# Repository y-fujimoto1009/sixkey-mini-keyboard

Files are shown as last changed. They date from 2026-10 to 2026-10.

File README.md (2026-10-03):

# 6キー ミニキーボード（RP2040-Zero）

RP2040-Zero、6個のMX互換キースイッチ、押し込み付きEC11エンコーダー、0.96インチST7735 LCDを使ったミニキーボードです。

## キー配置を設定する

**[キーマップ設定サイトを開く](https://y-fujimoto1009.github.io/sixkey-mini-keyboard/)**

6個のキーとエンコーダーの右回転・左回転・押し込みに操作を割り当て、設定JSONを保存できます。USB経由で本体を設定するときは、パソコン版Chrome / Edgeと対応ファームウェアを使用します。

上段はK4・K5・K6、下段はK1・K2・K3です。サイトのUSB接続後、読み込み・保存はそれぞれのボタンで行います。

## 本体LCDで遊ぶミニゲーム

現行は**Play V2.4**です。Command+C/V/X/Z/S/AとAlt+A/Vを追加しました。既存のCtrl設定は変更しません。Macでは設定サイトの「Mac（Command）」から選択し、USB設定にはChrome / Edgeを使います。AltはMacではOptionです。追加操作にはConfig V1.2またはPlay V2.4への本体更新が必要です。Ctrlと文字を同時に送る修正も維持しています。Mac実機での動作確認は未完了です。本体の色確認画面でRGB/BGRと反転設定を切り替え、実物に合う設定を保存できます。実機での表示・保存確認は未完了です。

[設定サイトのミニゲーム欄](https://y-fujimoto1009.github.io/sixkey-mini-keyboard/#games)から、[3ゲーム入りUF2](docs/sixkey-play-v2.4.uf2)をダウンロードできます。

- **うさぎのぴょんぴょん散歩**：ジャンプで20個のきのこを飛び越えるアクション。
- **ねこのおやつあつめ**：左右に動いていちごを20個集めるキャッチゲーム。
- **お花のきおくあそび**：光る順番を覚え、K1〜K3で答える8段の記憶パズル。

BOOT接続してRPI-RP2にUF2をコピーすると、3つまとめて本体に入ります。ゲーム中はPCへのHID入力を止めます。ゲームの進行は10項目のCPUエミュレーター検証、サイトの接続処理は模擬シリアル通信で検証済みです。キーボード機能とキー設定の保存形式も含む共通ファームです。

メニューではK1・K3で選択、K2で決定。ゲーム中K6でメニュー、終了後K2でリトライ。メニューのK6でキーボードへ戻ります。キーボードからはK4+K6を約1.2秒長押し（割り当て済みの入力もPCへ送信）。サイトのUSB開始ボタンからもゲームを選べます。

[ゲーム入りソース](firmware/SixKey_Play/)と[通信・ビルド仕様](docs/protocol.md)を公開しています。実機への書き込み・LCD表示・ゲーム操作・設定保持は未検証です。

## ダウンロード

| 内容 | ファイル |
| --- | --- |
| Rev8 ガーバー・ドリル一式 | [Gerber ZIP](hardware/sixkey-rev8-gerbers.zip) |
| 回路図 | [Rev8 回路図PDF](hardware/schematic-rev8.pdf) |
| 部品付き基板の3Dモデル（mm） | [STL](models/keyboard-assembly-mm.stl) / [STEP](models/keyboard-assembly.step) |
| 基板だけの3Dモデル（mm） | [STL](models/pcb-only-mm.stl) |
| 個別部品を含む3Dモデル一式 | [3Dモデル ZIP](models/sixkey-3d-models.zip) |
| 設定サイト用ファームウェア | [UF2](docs/sixkey-config-v1.2.uf2) / [ソース](firmware/SixKey_Config/SixKey_Config.ino) |

ガーバーの版と確認範囲は[基板の説明](hardware/README.md)、Tinkercadへの取り込み方法と仮寸法は[3Dモデルの説明](models/README.md)を参照してください。

## 確認状況

設定JSON、75種類の割り当て、ファームウェアとの操作番号の一致、UF2形式はソフトウェア検証済みです。本体へのUSB書き込み・電源再投入後の保持・新しいファームウェアのLCD/HID動作は実機未検証です。

UF2を書き込むと本体の既存ファームウェアを置き換えます。設定サイト内の手順を確認してください。[通信仕様](docs/protocol.md)も公開しています。

## サイトを更新する

`docs/`がGitHub Pagesの公開フォルダーです。`main`へ更新をpushするとサイトが更新されます。Node.jsで`npm test`を実行するとソフトウェア検証を行えます。

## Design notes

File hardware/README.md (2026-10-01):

# Rev8 基板データ

既存のRev8製造出力を保存した参照データです。別の版のファイルは混在させていません。

- 基板外形：84 × 73.05 mm、想定板厚1.6 mm。
- 表裏の銅箔・レジスト・シルク、外形、PTH/NPTHドリル、GerberジョブファイルをZIPに収録。
- 元のRev8ソースの確認記録ではERC・DRC・未接続・回路図との不一致は0件。
- 穴はPTH 50か所、NPTH 26か所。基板固定穴4か所とLCD固定穴4か所を含みます。

元プロジェクトの注意事項：Rev8を発注する場合は、対象プロジェクトからGerberとドリルを新規生成して最終確認してください。この公開は既存出力の共有であり、新たな製造承認を示すものではありません。

`SHA256SUMS.txt`で公開ファイルのハッシュを確認できます。

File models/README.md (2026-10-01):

# ケース設計用3Dモデル

## Tinkercadで使う

1. `keyboard-assembly-mm.stl`をダウンロードする。
2. Tinkercadの新しいデザインで「インポート」を開き、STLを選ぶ。
3. 単位はmm、倍率は100%にする。部品付きモデルの幅は約84 mmです。
4. モデルを基準にケースを作る。完成後はケースだけを選択してSTLをエクスポートする。

基板だけを使う場合は`pcb-only-mm.stl`、CADで扱う場合はSTEPを使います。`parts/`にはRP2040-Zero、LCD、EC11＋ノブ、MXスイッチ＋キーキャップの個別モデルを収録しています。

## 寸法・確認範囲

- 基板：84 × 73.05 × 1.6 mm。
- 部品付きSTLの外接寸法：約84 × 73.255 × 34.3 mm。
- STLは閉じたメッシュとして検証済み。Tinkercadへの実際の取り込みとケースの実物適合は未確認です。
- LCDの基板からの突出10.5 mm、RP2040-Zeroの裏面突出8.7 mm、EC11の軸・ノブ寸法、MXスイッチ・キーキャップ高さは仮寸法です。実物で確認してください。
- はんだの盛り、端子の突出、ネジ頭、USBケーブルのプラグ、キーの動作範囲を完全には再現していません。ケースにはこれらの余裕も確保してください。
- STEP内の長穴は小さい側の穴径の円で簡略化しています。基板STLは元のドリル形状を反映しています。

このモデルは配置とケース検討の参考モデルです。

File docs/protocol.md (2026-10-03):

# 6キー設定 V1

JSON: format = sixkey-keymap, version = 1, keys = K1〜K6の6要素。
encoder.clockwise / counterclockwise / press が回転・押し込み。
割り当て番号の定義は model.js の actions にあり、ファームの validAction と対応。

USB CDC 115200 bps / LF終端、ASCII。
読み出し: `K6/1 GET`
保存: `K6/1 SET 49,50,51,52,53,54,2001,2002,2003`
応答: `K6/1 MAP ` に続いて上記9番号。拒否: `K6/1 ERR 理由`。
保存時は入力を検証し、HIDを解放、EEPROMエミュレーションへ保存して物理フラッシュを読み戻す。
サイトはACKと再取得を照合する。再接続後の保持は実機で確認すること。
フラッシュ書き込み中の電源断では初期設定へ戻る可能性がある。

初期値: K1〜K6 = 1〜6、右回転 = 音量上、左回転 = 音量下、押し込み = ミュート。
英字の表示は大文字だが、送信は通常の文字キー（大文字化はShift/Caps Lock依存）。
キーと押し込みは押している間有効。エンコーダー回転とメディア操作は短い入力。
同時押しはUSBの6キー制限がある。CtrlショートカットはWindows/Linux向け。
V1はゲームを含みません。Play V2は3ゲームとキーボードを含みます。更新は利用者がBOOTモードで明示的に行います。

ビルド: Arduino-Pico 5.5.0、Waveshare RP2040 Zero、125MHz、2MB Flash / no filesystem、Pico SDK USB。
ライブラリ: Adafruit GFX、Adafruit ST7735/ST7789、コア標準Keyboard・SPI・EEPROM。
配線: LCD SCK=GP2, MOSI=GP3, DC=GP4, CS=GP5, RESET=GP6, BLK=GP7。
K1〜K6=GP26,27,28,13,14,15。エンコーダーA/B/押し込み=GP10,11,12。
液晶初期化と回転は動作実績のある設定を維持。実機での新ファーム動作は未検証。

## Play V2（ゲーム入り）

`K6/1 CAPS` → `K6/1 CAPS PLAY2`。旧V1は未対応コマンドとしてERRを返します。
`K6/1 GAME 0` → キーボード、1 → ジャンプ、2 → キャッチ、3 → 記憶パズル。
応答は`K6/1 GAME 番号`。0〜3の単一数字だけを受け付けます。
切り替え時はHIDを解放し、全キーを離して500ms経過するまで入力を受け付けません。
ゲーム中はHIDキー・メディア操作を送信しません。GET/SETによるキー設定は維持し、SETが成功するとキーボードへ戻ります。
モードはRAM内だけで管理し、電源投入時はゲームメニューです。K1で前、K3で次、K2で決定、K6でキーボードへ。
ゲーム中はK6でメニュー、終了後はK2でリトライ。キーボード中はK4+K6を約1.2秒長押しでメニューへ戻ります。この長押しでは割り当て済みのキー入力もPCに送られます。

Play V2ソースは`firmware/SixKey_Play/`の2ファイルを同じフォルダーに置きます。ボードとライブラリはV1と同じです。

```sh
arduino-cli compile --fqbn rp2040:rp2040:waveshare_rp2040_zero:flash=2097152_0,freq=125,usbstack=picosdk --output-dir build firmware/SixKey_Play
```

ゲームロジックのCortex-M0エミュレーター検証は`tests/README.md`を参照してください。LCD・USB・GPIOと実物の遊び心地は実機未検証です。

### Play V2.1：液晶の色順を修正

利用者の実機報告「赤と青が入れ替わる」に対応し、MINI160x80の初期化・回転3の後でMADCTLをMX | MV | BGRに設定します。回転・オフセット・RGB565描画データは変更しません。赤青の順序だけを変更し、通信仕様のCAPS PLAY2も維持します。修正後の実機表示確認は未完了です。

### Play V2.2：色の確認と保存

初回（表示設定なし）は色確認画面。K1でRGB/BGR、K2でINVON/INVOFFを切り替え、K5でEEPROMの64番地に表示設定を保存して物理フラッシュを読み戻します。保存成功はSAVED表示。キー設定と保存領域は重なりません。K6でメニューへ。保存後の起動はメニューになり、メニューK4で再調整できます。正しい色順と反転設定は実機のテストパターンで判断するもので、こちらでは未確定です。

## Config V1.2 / Play V2.4：Mac・Alt

1001〜1006は従来どおりCtrl+C/V/X/Z/S/A。1101〜1106はCommand+C/V/X/Z/S/A（左GUI修飾、HIDマスク0x08）。1201・1202はAlt+A・Alt+V（左Alt修飾、0x04）。MacではAltはOptionとして動作し、結果はアプリ・入力言語に依存します。既存設定をOSに応じて自動変換しません。

設定ファイルversionと通信K6/1は維持。新しい操作IDを保存する前に本体も更新してください。旧ファームは新IDを拒否します。MacのUSB設定にはWeb Serial対応のChrome / Edgeを使用します。Mac実機でのHID・保存・再起動は未検証です。

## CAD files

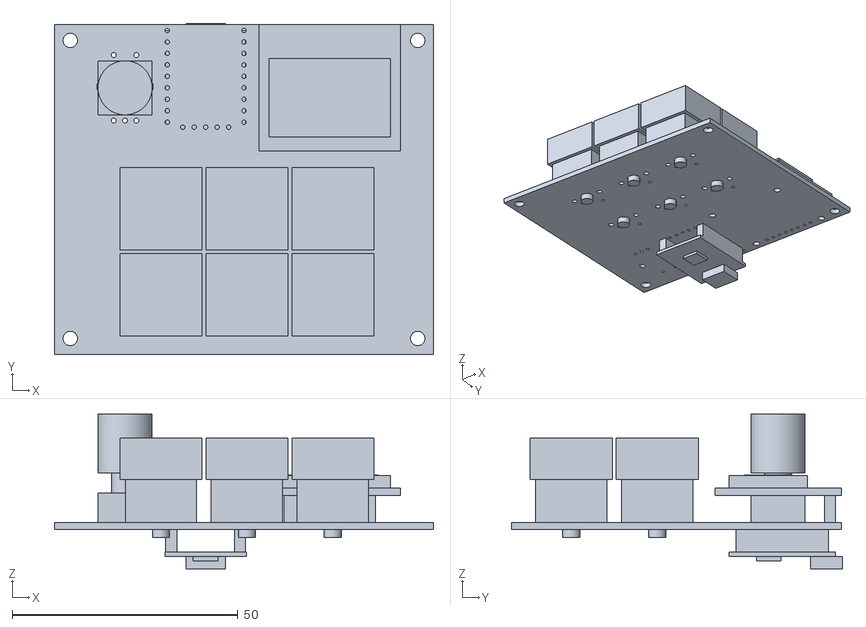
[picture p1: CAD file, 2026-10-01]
models/keyboard-assembly-mm.stl
84.0 x 73.3 x 34.3

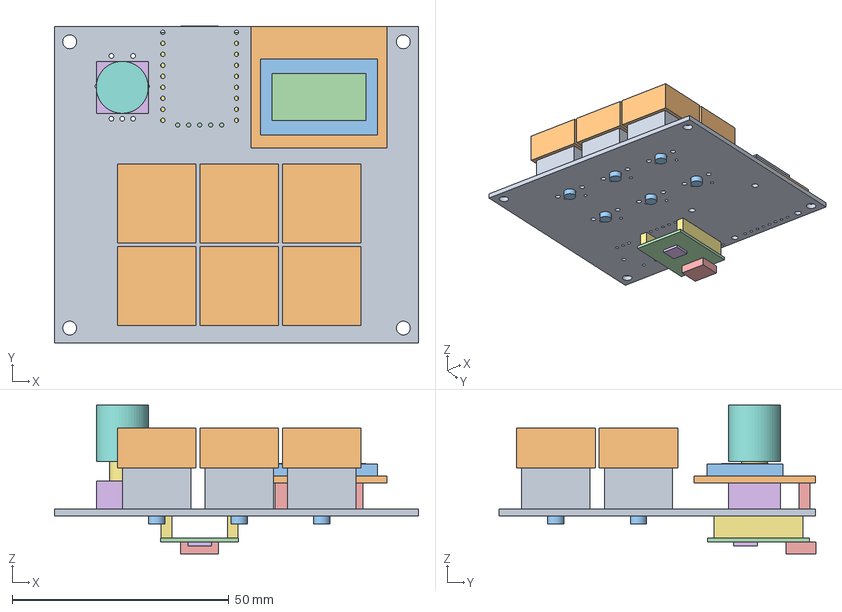
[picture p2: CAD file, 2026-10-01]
models/keyboard-assembly.step
84.0 x 73.3 x 34.3 mm

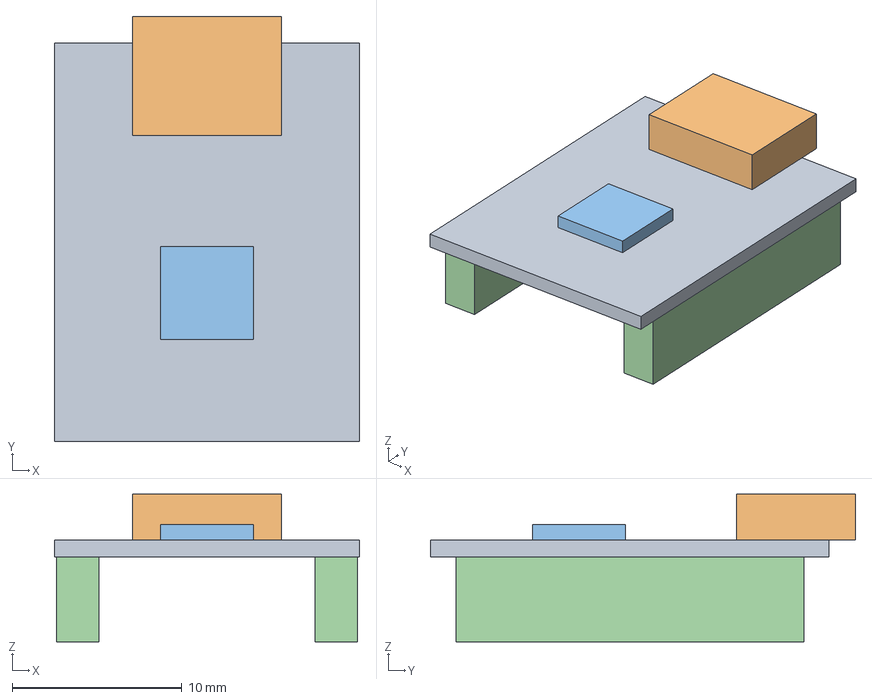
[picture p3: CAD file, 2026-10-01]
models/parts/RP2040_ZERO.step
18.0 x 25.1 x 8.70 mm

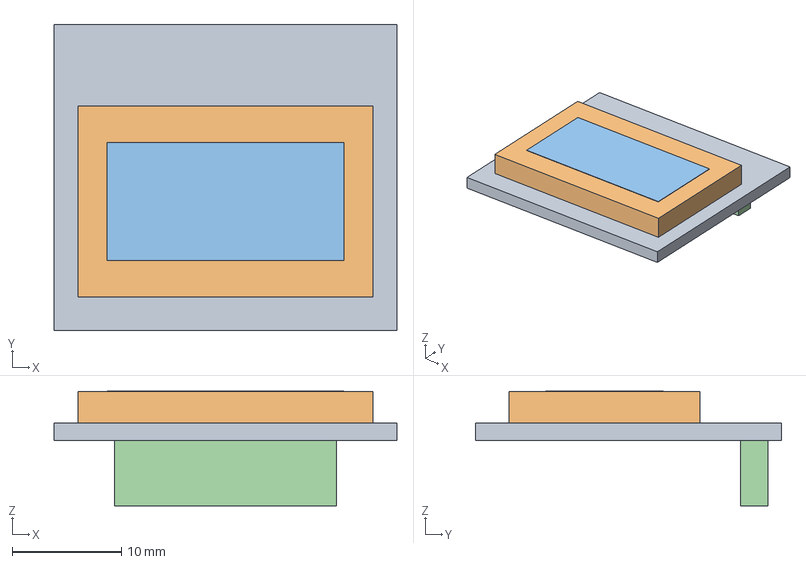
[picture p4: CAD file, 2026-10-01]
models/parts/LCD_ST7735.step
31.4 x 28.0 x 10.5 mm

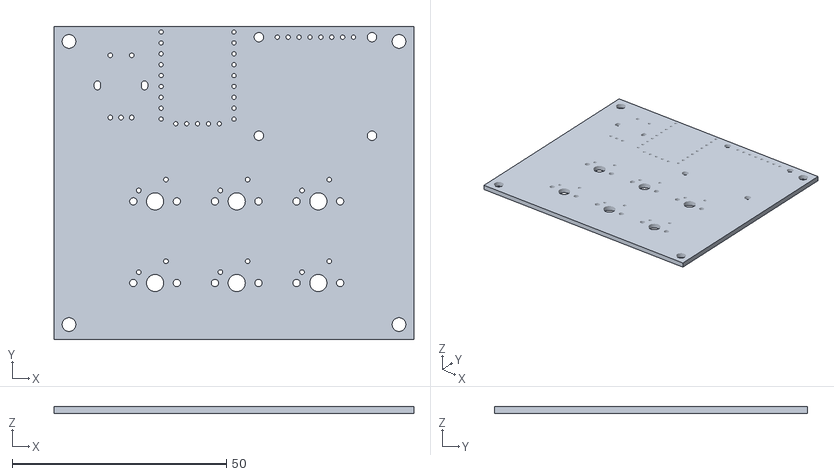
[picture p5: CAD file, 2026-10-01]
models/pcb-only-mm.stl
84.0 x 73.0 x 1.60

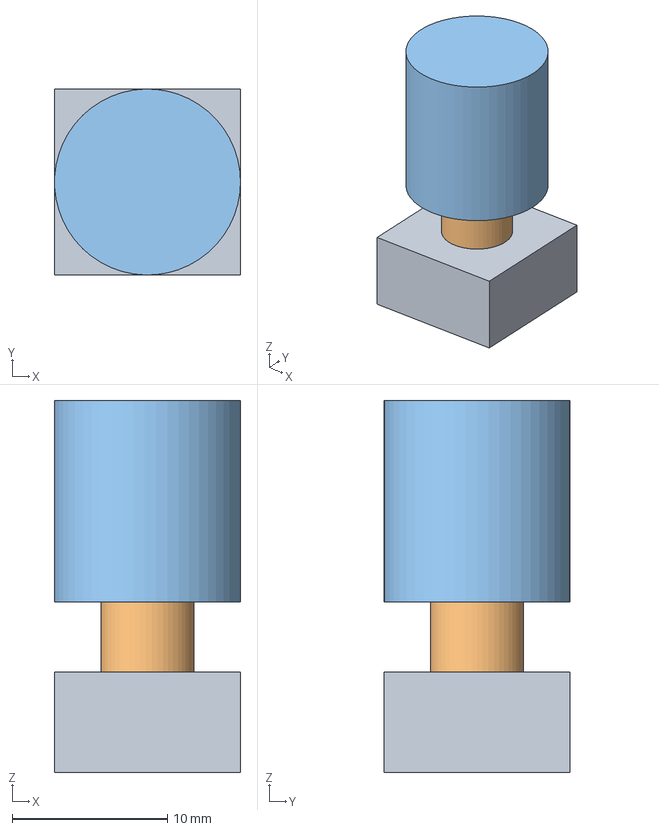
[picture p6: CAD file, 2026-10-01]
models/parts/EC11_WITH_KNOB.step
12.0 x 12.0 x 24.0 mm

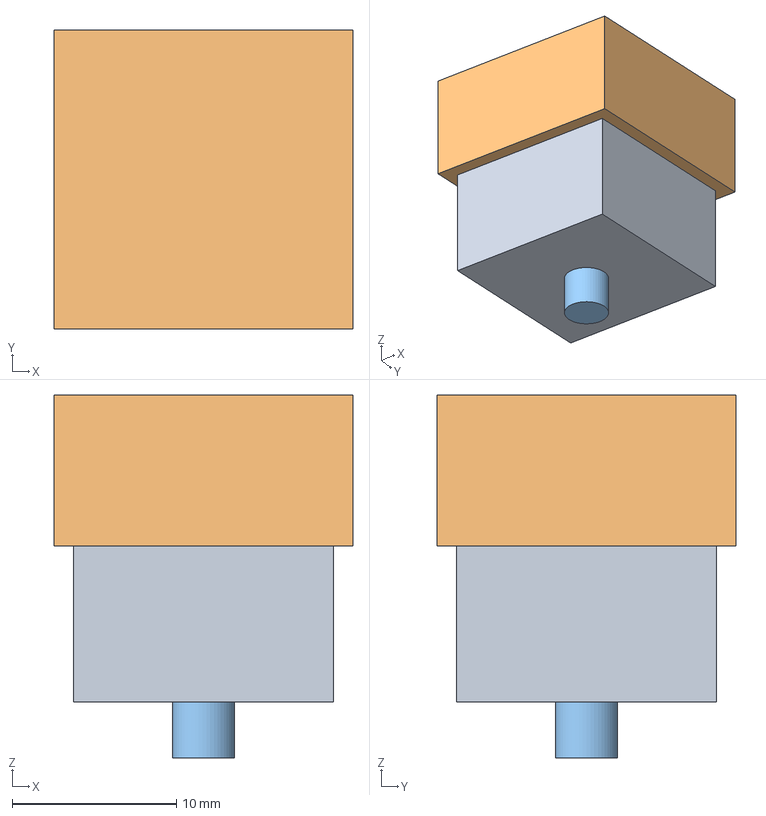
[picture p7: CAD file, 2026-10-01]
models/parts/MX_WITH_KEYCAP.step
18.2 x 18.2 x 22.1 mm

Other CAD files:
models/parts/EC11_WITH_KNOB.obj
models/parts/EC11_WITH_KNOB.stl
models/parts/LCD_ST7735.obj
models/parts/LCD_ST7735.stl
models/parts/MX_WITH_KEYCAP.obj
models/parts/MX_WITH_KEYCAP.stl
models/parts/RP2040_ZERO.obj
models/parts/RP2040_ZERO.stl

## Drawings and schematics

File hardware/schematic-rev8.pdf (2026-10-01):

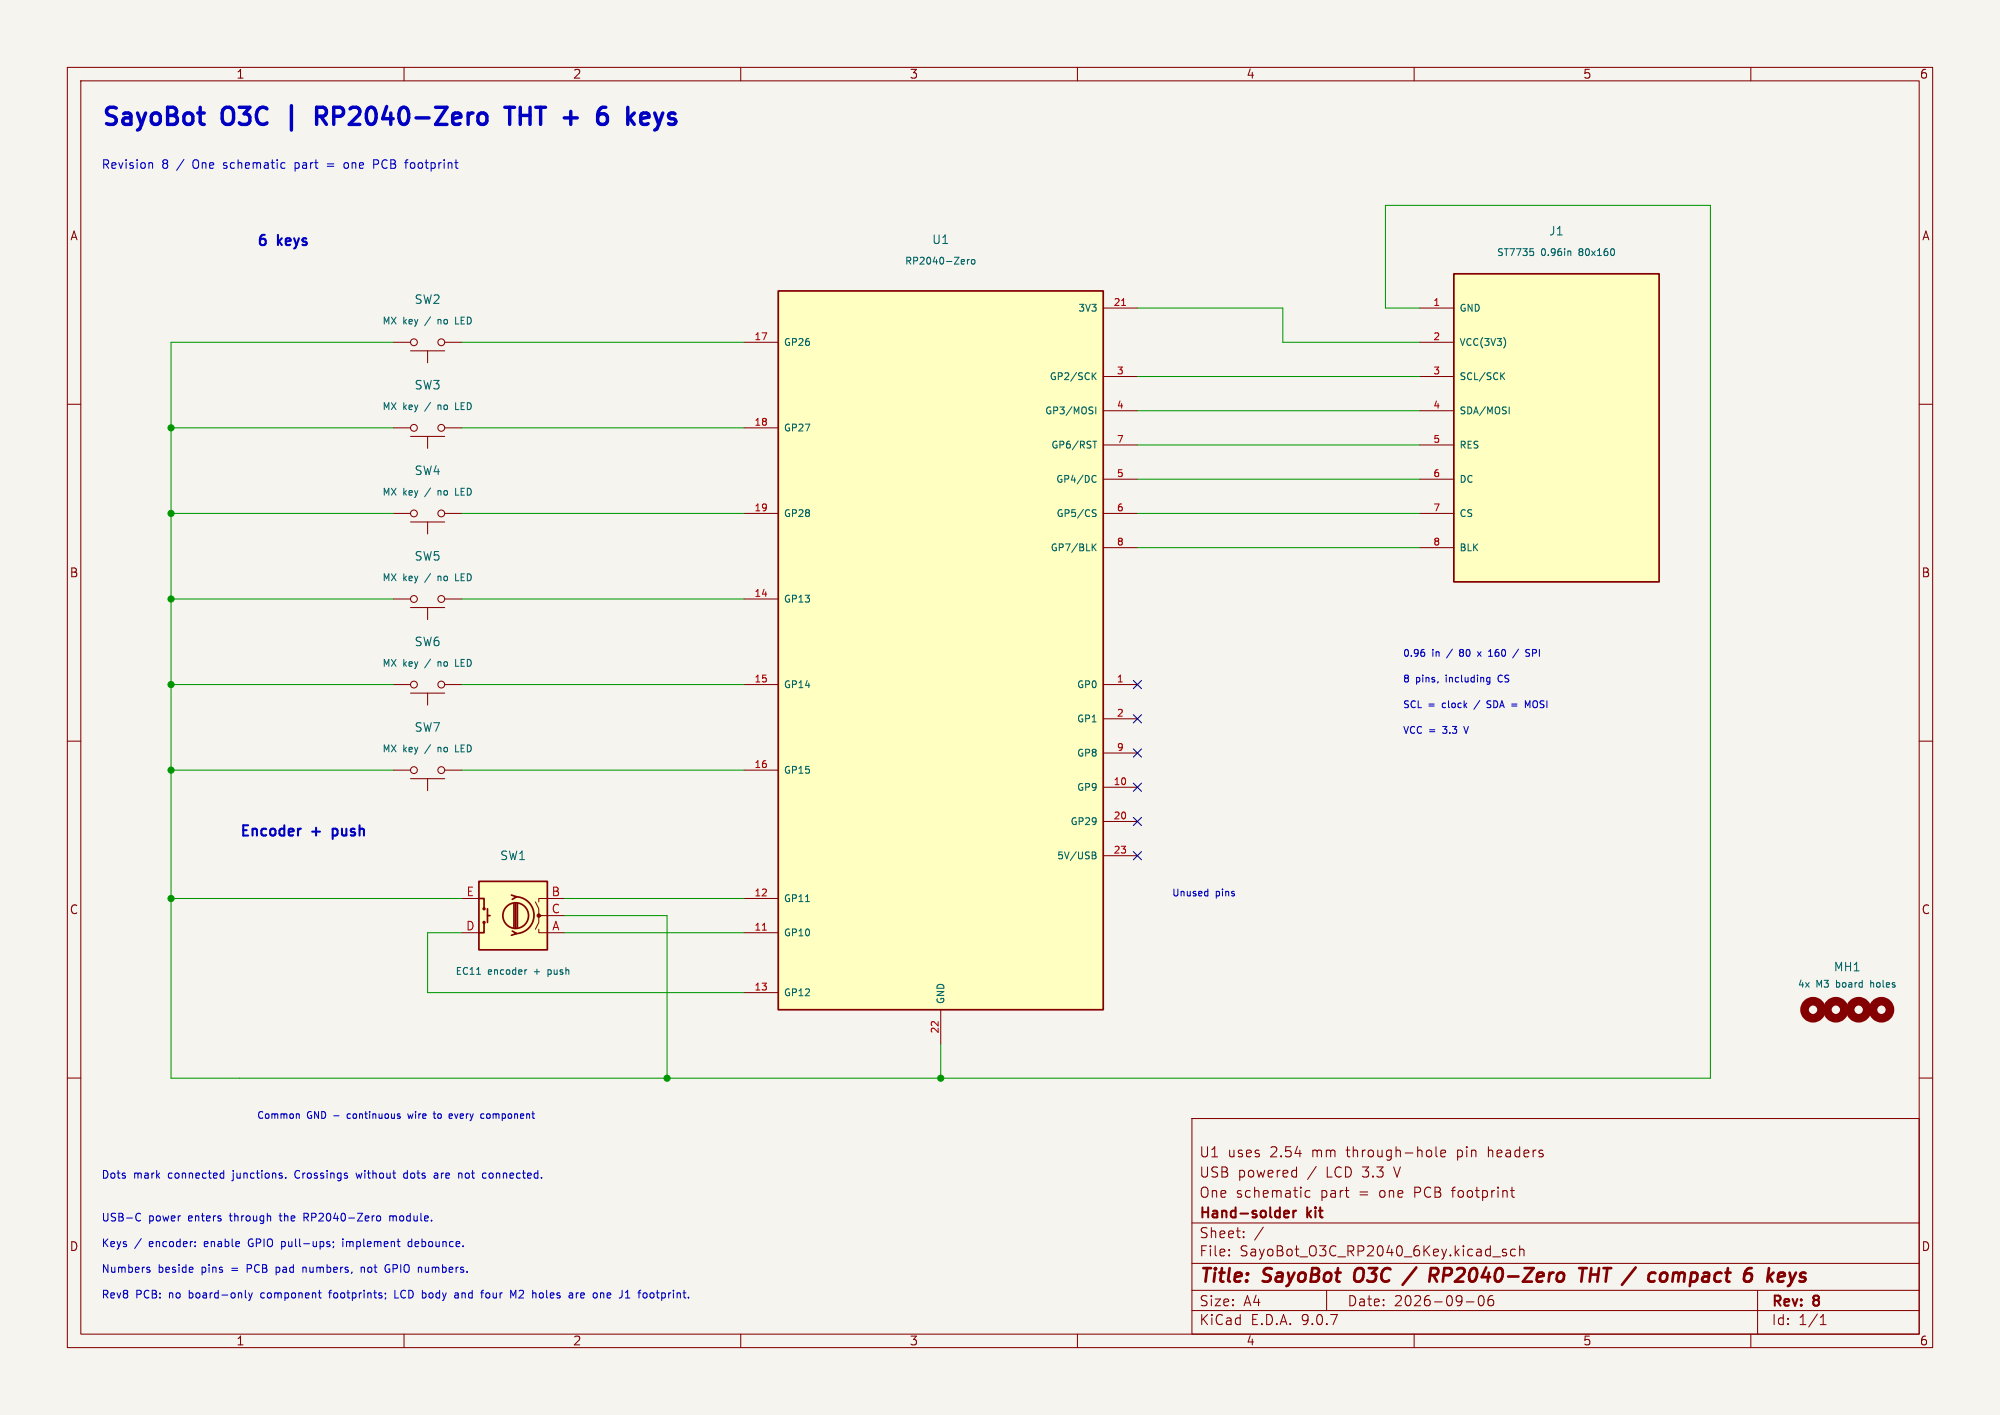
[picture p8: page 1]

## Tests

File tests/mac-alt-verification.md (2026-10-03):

# Mac / Alt update — 2026-10-03

- Config V1.2 and Play V2.4 compiled successfully for Waveshare RP2040 Zero with Arduino-Pico 5.5.0.
- Authoritative modifier definitions: installed HID_Keyboard.h defines left Ctrl=128, Alt=130, GUI=131. The HID implementation maps them to modifier bits 0x01, 0x04, 0x08.
- Mac Command uses GUI; Alt is Option. Reference: https://support.apple.com/en-us/102650
- Mac USB configuration requires desktop Web Serial support, e.g. Chrome: https://developer.chrome.com/docs/capabilities/serial
- npm test passed: all 83 action IDs match both firmware validators, JSON/serial round trips, invalid input rejection, downloadable source equality, UF2 structure and game compatibility.
- Actual addAction/syncHeld/tap bodies were exercised with modeled USB transport for all 14 Ctrl/Command/Alt shortcuts. Chords are emitted together and release correctly.
- Real app.js was exercised against a simulated serial device: Command, Alt and existing Ctrl settings saved and read back through the UI.
- Both downloadable UF2 payloads were byte-compared with their compiled BIN files. Flash addresses exclude the EEPROM sector.
- Existing Ctrl IDs, GPIO assignments, keymap format, games and display settings are preserved. New IDs require the updated firmware.

Not verified: physical Mac/Windows USB HID operation, physical flash writes, power-cycle persistence, LCD appearance. Automated transport tests are simulations, not device tests.

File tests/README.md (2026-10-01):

# ゲームロジックの検証

`Games.h`をCortex-M0向けにコンパイルし、Unicornで実行します。メニュー選択、ジャンプの失敗と20個クリア、キャッチの移動端・失敗・クリア、記憶パズルの入力待ち・8段クリア・間違いを検証します。

描画はスタブ、LCD・USB・GPIOなどの周辺機器は未再現です。実機確認の代わりにはなりません。

```sh
python -m pip install unicorn pyelftools
arm-none-eabi-g++ -mcpu=cortex-m0plus -mthumb -Os -ffreestanding -fno-exceptions -fno-rtti -nostdlib -I tests tests/game_logic.cpp -Wl,-Ttext=0x10000000,-Tdata=0x20000000,-e,run_game_tests -lc -lgcc -o game-tests.elf
python tests/run_arm_tests.py game-tests.elf
```

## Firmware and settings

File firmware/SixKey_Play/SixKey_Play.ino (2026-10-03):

#include <Adafruit_GFX.h>
#include <Adafruit_ST7735.h>
#include <Keyboard.h>
#include <SPI.h>
#include <EEPROM.h>
#include <USB.h>
#include <tusb.h>

// Build a complete chord before sending it. Sending ASCII first and Ctrl
// second produces a plain letter; a busy USB endpoint can also drop Ctrl.
class ChordKeyboard : public Keyboard_ {
  KeyReport pendingReport={};
  bool pendingReportDirty=false;
protected:
  void sendReport(KeyReport *report) override {
    pendingReport=*report;
    pendingReportDirty=true;
  }
public:
  bool flushReport() {
    if(!pendingReportDirty)return true;
    if(!_running)return false;
    CoreMutex lock(&USB.mutex);
    tud_task();
    if(USB.HIDReady() && tud_hid_keyboard_report(USB.findHIDReportID(_id),pendingReport.modifiers,pendingReport.keys))pendingReportDirty=false;
    tud_task();
    return !pendingReportDirty;
  }
  bool waitReport() {
    uint32_t started=millis();
    while(!flushReport()) {
      if(millis()-started>=40)return false;
      delay(1);
    }
    return true;
  }
};
ChordKeyboard chordKeyboard;
#include "Games.h"
GFXcanvas16 frame(160,80);
uint32_t gameFrameAt=0,menuHoldAt=0;
bool menuChordLatched=false;
constexpr TinyGames::Scene COLOR_TEST=static_cast<TinyGames::Scene>(5);
constexpr int DISPLAY_CONFIG_OFFSET=64;
struct DisplayConfig { uint32_t magic;uint8_t bgr,invert,check,reserved; };
DisplayConfig displayConfig={0x434f4c32,1,1,0xa6,0};
bool displaySaved=false;
void applyDisplay();
void drawColorTest();
void setScene(TinyGames::Scene scene);
void drawGame();

// RP2040-Zero: preserve the pin assignments of the working hardware.
constexpr uint8_t KEY_PINS[7]={26,27,28,13,14,15,12};
constexpr uint8_t LCD_SCK=2,LCD_MOSI=3,LCD_DC=4,LCD_CS=5,LCD_RST=6,LCD_BLK=7;
constexpr uint8_t ENC_A=10,ENC_B=11;
constexpr uint16_t DEFAULTS[9]={49,50,51,52,53,54,2001,2002,2003};
constexpr uint32_t MAGIC=0x364b0001;
struct Config{uint32_t magic;uint16_t map[9];uint16_t checksum;};
static_assert(sizeof(Config)<=DISPLAY_CONFIG_OFFSET,"Display settings must not overlap keymap");
struct Button{bool raw,down;uint32_t changed;};
Config config;
Button buttons[7];
bool sent[256]={},armed=false;
uint32_t releasedAt=0;
uint8_t encPrevious;
int8_t quarters=0;
char line[120];size_t used=0;bool overflow=false;
Adafruit_ST7735 tft(&SPI,LCD_CS,LCD_DC,LCD_RST);

bool validAction(uint16_t a){return a==0||a==32||(a>=48&&a<=57)||(a>=97&&a<=122)||(a>=128&&a<=131)||(a>=176&&a<=179)||(a>=194&&a<=205)||(a>=212&&a<=212)||(a>=215&&a<=218)||(a>=1001&&a<=1006)||(a>=1101&&a<=1106)||(a>=1201&&a<=1202)||(a>=2001&&a<=2006);}
uint16_t checksum(const Config &c){uint16_t h=0x6b31;for(auto a:c.map)h=(h*31)^a;return h;}
bool validConfig(const Config &c){if(c.magic!=MAGIC||c.checksum!=checksum(c))return false;for(auto a:c.map)if(!validAction(a))return false;return true;}
void releaseHid(){chordKeyboard.releaseAll();chordKeyboard.waitReport();chordKeyboard.consumerRelease();memset(sent,0,sizeof(sent));}
void draw(){if(TinyGames::scene!=TinyGames::KEYS){drawGame();return;}tft.fillScreen(ST77XX_BLACK);tft.setTextSize(1);tft.setTextColor(ST77XX_WHITE);tft.setCursor(3,3);tft.print("6KEY PLAY V2.4");for(int i=0;i<6;i++){int x=(i%3)*53,y=18+(i<3?23:0);tft.fillRoundRect(x+1,y,50,20,3,buttons[i].down?ST77XX_GREEN:ST77XX_BLUE);tft.setCursor(x+4,y+6);tft.print(i+1);tft.print(':');tft.print(config.map[i]);}tft.setCursor(3,68);tft.print(armed?"K4+K6: MENU":"Release all keys");}
void report(){Serial.print("K6/1 MAP ");for(int i=0;i<9;i++){if(i)Serial.print(',');Serial.print(config.map[i]);}Serial.println();}
void command(){
  line[used]=0;
  if(!strcmp(line,"K6/1 CAPS")){Serial.println("K6/1 CAPS PLAY2");return;}
  if(!strncmp(line,"K6/1 GAME ",10)){
    if(line[10]>='0'&&line[10]<='3'&&line[11]==0){int id=line[10]-'0';setScene(id==0?TinyGames::KEYS:static_cast<TinyGames::Scene>(id));Serial.print("K6/1 GAME ");Serial.println(id);}else Serial.println("K6/1 ERR GAME");return;
  }
  if(!strcmp(line,"K6/1 GET")){report();return;}
  if(strncmp(line,"K6/1 SET ",9)){Serial.println("K6/1 ERR COMMAND");return;}
  Config next={};next.magic=MAGIC;const char *p=line+9;
  for(int i=0;i<9;i++){
    if(*p<'0'||*p>'9'){Serial.println("K6/1 ERR FORMAT");return;}
    unsigned value=0;while(*p>='0'&&*p<='9'){value=value*10+(*p++-'0');if(value>3000){Serial.println("K6/1 ERR RANGE");return;}}
    if(!validAction(value)||(*p!=(i==8?'\0':','))){Serial.println("K6/1 ERR VALUE");return;}
    next.map[i]=value;if(i<8)p++;
  }
  next.checksum=checksum(next);releaseHid();armed=false;releasedAt=0;quarters=0;
  EEPROM.put(0,next);if(!EEPROM.commit()){Serial.println("K6/1 ERR FLASH");return;}
  // begin() re-reads physical flash rather than merely checking the RAM buffer.
  EEPROM.begin(256);Config saved={};EEPROM.get(0,saved);
  if(!validConfig(saved)||memcmp(&saved,&next,sizeof(next))){Serial.println("K6/1 ERR VERIFY");return;}
  config=saved;setScene(TinyGames::KEYS);draw();report();
}
void serialPoll(){int budget=128;while(Serial.available()&&budget--){char c=Serial.read();if(c=='\r')continue;if(c=='\n'){if(overflow)Serial.println("K6/1 ERR LENGTH");else command();used=0;overflow=false;}else if(used<sizeof(line)-1&&!overflow)line[used++]=c;else overflow=true;}}
void addAction(bool *desired,uint16_t a){if(a>0&&a<256)desired[a]=true;else if(a>=1001&&a<=1006){const char keys[]="cvxzsa";desired[KEY_LEFT_CTRL]=true;desired[(uint8_t)keys[a-1001]]=true;}else if(a>=1101&&a<=1106){const char keys[]="cvxzsa";desired[KEY_LEFT_GUI]=true;desired[(uint8_t)keys[a-1101]]=true;}else if(a>=1201&&a<=1202){const char keys[]="av";desired[KEY_LEFT_ALT]=true;desired[(uint8_t)keys[a-1201]]=true;}}
void mediaTap(uint16_t a){if(a<2001||a>2006)return;const uint16_t codes[]={0xe9,0xea,0xe2,0xcd,0xb5,0xb6};chordKeyboard.consumerPress(codes[a-2001]);delay(12);chordKeyboard.consumerRelease();}
void syncHeld(){bool desired[256]={};for(int i=0;i<7;i++)if(buttons[i].down)addAction(desired,config.map[i==6?8:i]);for(int i=1;i<256;i++)if(sent[i]&&!desired[i])chordKeyboard.release(i);for(int i=1;i<256;i++)if(!sent[i]&&desired[i])chordKeyboard.press(i);memcpy(sent,desired,sizeof(sent));chordKeyboard.flushReport();}
void tap(uint16_t a){if(a>=2001){mediaTap(a);return;}bool desired[256]={};addAction(desired,a);for(int i=1;i<256;i++)if(desired[i]&&!sent[i])chordKeyboard.press(i);if(chordKeyboard.waitReport())delay(12);for(int i=1;i<256;i++)if(desired[i]&&!sent[i])chordKeyboard.release(i);chordKeyboard.waitReport();}
void setup(){
  pinMode(LCD_BLK,OUTPUT);digitalWrite(LCD_BLK,LOW);
  for(int i=0;i<7;i++){pinMode(KEY_PINS[i],INPUT_PULLUP);buttons[i]={digitalRead(KEY_PINS[i])==LOW,digitalRead(KEY_PINS[i])==LOW,millis()};}
  pinMode(ENC_A,INPUT_PULLUP);pinMode(ENC_B,INPUT_PULLUP);encPrevious=(digitalRead(ENC_A)<<1)|digitalRead(ENC_B);
  EEPROM.begin(256);EEPROM.get(0,config);if(!validConfig(config)){config={};config.magic=MAGIC;memcpy(config.map,DEFAULTS,sizeof(DEFAULTS));config.checksum=checksum(config);}
  DisplayConfig stored={};EEPROM.get(DISPLAY_CONFIG_OFFSET,stored);
  displaySaved=stored.magic==0x434f4c32&&stored.bgr<=1&&stored.invert<=1&&stored.check==(0xa5^stored.bgr^(stored.invert<<1));
  if(displaySaved)displayConfig=stored;
  Serial.begin(115200);chordKeyboard.begin();releaseHid();
  SPI.setSCK(LCD_SCK);SPI.setTX(LCD_MOSI);SPI.begin();tft.initR(INITR_MINI160x80);tft.setRotation(3);
  applyDisplay();
  if(!displaySaved)TinyGames::scene=COLOR_TEST;
  draw();digitalWrite(LCD_BLK,HIGH);
}

void applyDisplay(){
  uint8_t madctl=ST77XX_MADCTL_MX|ST77XX_MADCTL_MV|(displayConfig.bgr?ST7735_MADCTL_BGR:ST77XX_MADCTL_RGB);
  tft.sendCommand(ST77XX_MADCTL,&madctl,1);tft.invertDisplay(displayConfig.invert!=0);
}
void drawColorTest(){
  frame.fillScreen(ST77XX_BLACK);frame.setTextSize(1);frame.setTextColor(ST77XX_WHITE);frame.setCursor(3,2);frame.print("COLOR TEST V2.4");
  frame.setCursor(3,13);frame.print(displayConfig.bgr?"BGR":"RGB");frame.print(displayConfig.invert?" INV:ON":" INV:OFF");frame.print(displaySaved?" SAVED":"");
  const uint16_t colors[]={ST77XX_RED,ST77XX_GREEN,ST77XX_BLUE};const char *names[]={"RED","GREEN","BLUE"};
  for(int i=0;i<3;i++){frame.fillRect(2+i*53,24,49,18,colors[i]);frame.setTextColor(i==1?ST77XX_BLACK:ST77XX_WHITE);frame.setCursor(6+i*53,29);frame.print(names[i]);}
  frame.drawRect(2,45,75,12,ST77XX_WHITE);frame.setTextColor(ST77XX_WHITE);frame.setCursor(7,48);frame.print("BLACK");
  frame.fillRect(82,45,75,12,ST77XX_WHITE);frame.setTextColor(ST77XX_BLACK);frame.setCursor(87,48);frame.print("WHITE");
  frame.setTextColor(ST77XX_WHITE);frame.setCursor(3,60);frame.print("K1:RGB K2:INV");frame.setCursor(3,71);frame.print("K5:SAVE K6:BACK");
  tft.drawRGBBitmap(0,0,frame.getBuffer(),160,80);
}
void drawGame(){if(TinyGames::scene==TinyGames::KEYS)return;if(TinyGames::scene==COLOR_TEST){drawColorTest();return;}TinyGames::draw(frame);tft.drawRGBBitmap(0,0,frame.getBuffer(),160,80);}
void setScene(TinyGames::Scene scene){
  releaseHid();armed=false;releasedAt=0;quarters=0;menuHoldAt=0;
  TinyGames::start(scene,millis());gameFrameAt=millis();draw();
}
void loop(){
  serialPoll();chordKeyboard.flushReport();uint32_t now=millis();bool released=true,changed=false;
  static bool pendingPress[7]={};
  for(int i=0;i<7;i++){
    auto &b=buttons[i];bool down=digitalRead(KEY_PINS[i])==LOW;
    if(down!=b.raw){b.raw=down;b.changed=now;}
    if(b.down!=b.raw&&now-b.changed>=8){
      b.down=b.raw;changed=true;
      if(armed&&b.down){pendingPress[i]=true;if(TinyGames::scene==TinyGames::KEYS)mediaTap(config.map[i==6?8:i]);}
    }
    released&=!b.down&&!b.raw;
  }
  if(!armed){if(released){if(!releasedAt)releasedAt=now;if(now-releasedAt>=500){armed=true;changed=true;}}else releasedAt=0;}
  // Keyboard mode uses a deliberate two-key hold to avoid accidental game launch.
  bool chord=buttons[3].down&&buttons[5].down;
  if(!chord){menuHoldAt=0;menuChordLatched=false;}
  if(TinyGames::scene==TinyGames::KEYS&&armed&&chord&&!menuChordLatched){
    if(!menuHoldAt)menuHoldAt=now;
    if(uint32_t(now-menuHoldAt)>=1200){menuChordLatched=true;setScene(TinyGames::MENU);memset(pendingPress,0,sizeof(pendingPress));}
  }
  uint8_t current=(digitalRead(ENC_A)<<1)|digitalRead(ENC_B);
  static const int8_t transitions[16]={0,-1,1,0,1,0,0,-1,-1,0,0,1,0,1,-1,0};
  if(current!=encPrevious){quarters+=transitions[(encPrevious<<2)|current];encPrevious=current;if(!armed||TinyGames::scene!=TinyGames::KEYS)quarters=0;else if(quarters>=4||quarters<=-4){tap(config.map[quarters>0?6:7]);quarters=0;}}
  if(TinyGames::scene==TinyGames::KEYS){
    if(armed)syncHeld();else chordKeyboard.flushReport();if(changed)draw();memset(pendingPress,0,sizeof(pendingPress));return;
  }
  if(uint32_t(now-gameFrameAt)<25)return;
  gameFrameAt=now;bool held[7];for(int i=0;i<7;i++)held[i]=armed&&buttons[i].down;
  if(TinyGames::scene==COLOR_TEST){
    if(armed&&pendingPress[5])setScene(TinyGames::MENU);
    else if(armed&&pendingPress[0]){displayConfig.bgr^=1;displaySaved=false;applyDisplay();}
    else if(armed&&pendingPress[1]){displayConfig.invert^=1;displaySaved=false;applyDisplay();}
    else if(armed&&pendingPress[4]){
      displayConfig.check=0xa5^displayConfig.bgr^(displayConfig.invert<<1);
      EEPROM.put(DISPLAY_CONFIG_OFFSET,displayConfig);bool committed=EEPROM.commit();
      EEPROM.begin(256);DisplayConfig checked={};EEPROM.get(DISPLAY_CONFIG_OFFSET,checked);
      displaySaved=committed&&memcmp(&checked,&displayConfig,sizeof(checked))==0;
    }
    memset(pendingPress,0,sizeof(pendingPress));drawGame();return;
  }
  if(armed&&pendingPress[3]&&TinyGames::scene==TinyGames::MENU)setScene(COLOR_TEST);
  else if(armed&&pendingPress[5])setScene(TinyGames::scene==TinyGames::MENU?TinyGames::KEYS:TinyGames::MENU);
  else if(armed&&pendingPress[1]&&TinyGames::scene==TinyGames::MENU)setScene(static_cast<TinyGames::Scene>(TinyGames::selected==3?TinyGames::KEYS:TinyGames::selected+1));
  else if(armed&&pendingPress[1]&&TinyGames::ended)setScene(TinyGames::scene);
  else if(armed)TinyGames::step(held,pendingPress,0,now);
  memset(pendingPress,0,sizeof(pendingPress));drawGame();
}

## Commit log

2026-10-01 Publish six-key configurator, Rev8 Gerbers and 3D models
    [EC11_WITH_KNOB.obj, EC11_WITH_KNOB.step, EC11_WITH_KNOB.stl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]
2026-10-01 Preserve exact file bytes and download checksums
    [EC11_WITH_KNOB.obj, LCD_ST7735.obj, MX_WITH_KEYCAP.obj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]
2026-10-01 Fix red-blue LCD swap with BGR mode in Play v2.1
    [SixKey_Play.ino]
2026-10-01 Enable display inversion and add persistent LCD color calibration in v2.2
2026-10-03 Fix Ctrl shortcut HID reports in keyboard and Play firmware
    [SixKey_Config.ino, SixKey_Play.ino]
2026-10-03 Add Mac Command shortcuts and Alt+A/V with updated firmware
    [SixKey_Config.ino, SixKey_Play.ino]
